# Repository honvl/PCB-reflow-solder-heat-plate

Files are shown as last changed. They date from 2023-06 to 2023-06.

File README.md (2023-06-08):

# PCB reflow solder heat plate

## Introduction

The PCB reflow solder heat plate can be used to solder small PCBs with SMD parts. The user can control the maximum temperature and heating curve. Buy a pre-assembled version here: https://www.tindie.com/products/littlethings/pcb-reflow-soldering-hot-plate/

## Hardware design

The idea for this design comes from https://github.com/AfterEarthLTD/Solder-Reflow-Plate. But when I checked the original design, I found some issues that could cause safety problems and other design choices that are not optimal.

## Hardware version 1.2

- Removed resettable fuse which was overheating and tripping
- Increased power supply capacitor ratings to 35V for 24V power supply compatibility
- Use 2 SMD capacitors for power supply capacitors instead of 4 standard ones for lower total board height
- Changed to easier to press switches

### Feature list

- PCB size 100x100mm, heat plate size 81x69mm
- DC barrel plug (5.5x2.5mm), runs with 12V/5A power supply
- inrush current limiter to protect power supply when capacitors are discharged
- 2.7mF input power filter for smooth current draw
- capacitor discharging resistors
- ATMEGA4809 MCU, can be programmed via UPDI header
- high power NMOS with gate driver circuit
- flyback diode connected to the heat plate
- AMS1117 LDO
- additional diodes for protection
- dual buttons
- status LED
- 0.91" OLED display
- LMT85 analog temperature sensor as main sensor
- option to add additional digital sensors for calibration purposes

### Building your own

You can order almost all parts needed from LCSC/JLCPCB. Only the OLED display and the power supply need to be sourced elsewhere. The BOM includes LCSC part numbers for hand soldering and their automated SMT manufacturing. Minimal part size is 0805 and there's enough space between all solder pads, so hand soldering should be no problem if you have a steady hand. Hardest part will be the MCU, but this is hand solderable, too.

### Safety measures compared to the original design

The original design had a too low heat plate resistance, which caused very high current spikes when the heat plate was turned on. This should be filtered by PWM and the input capacitors, but the input capacitor in the original design was far too small (100µF). Because of this, the fuse always blew when the device was turned on, so eventually the fuse was removed again.
In my design I made the input capacitors 27 times larger to have a smoother current draw. I also added a fuse, and an inrush current limiter. After disconnecting the power supply, the output capacitors are quickly discharged to GND.
The original also had no gate driver, so the NMOS was only driven with logic levels. I added a simple NPN gate driver.
Switching inductive loads (like the long heat plate trace) causes voltage spikes. In the original design, the filtering was done with an ESD diode and a small capacitor. The usual way to filter these voltage spikes is a flyback diode.
The resistance of the heat plate was very low, so the current draw with 100% PWM duty cycle was very high. If the MCUs hangs up and the power MOSFET stays active, the original design could cause too much stress for the power supply. Furthermore, even with a hot heat plate, the resistance would still be so low that the board would draw more than 5A.
In my design, the heat plate resistance was chosen in a way that a hot heat plate will draw less than 5A, so it is much safer to run the new design, as it will automatically reach electrically safe working conditions.

## Firmware

The original firmware was reworked by Nathan Heidt (https://github.com/heidtn) and works mostly, only the temperature sensing is incorrect (as the firmware was written with an earlier board revision). So for now, you just need to unplug the device when the PCB that needed soldering is done. Also, the dual color LED is not yet included into the code, for now it just lights green to show power. And the buttons sometimes don't react properly.

Daniel Oltmanns (https://github.com/oltdaniel) is doing a rework of the firmware using platformio.

### To-do list for software:
- use of the dual color LED (green = power, orange = heating, red = hot)
- better temperature sensing
- better working buttons
- calibration function for the analog temperature sensor by taping a digital probe directly to the heat plate

Please note that I can only do hardware design, so I can't contribute anything to the software. 

### Programming the MCU

The MCU can be programmed with JTAG2UPDI (https://github.com/ElTangas/jtag2updi). For programming, you need an Arduino with ATMEGA328p (Uno or Nano), some wires, a 4.7k resistor and  a 10µF capacitor or 120 Ohm resistor to disable the auto-reset.

JCM from the Discord explained the process pretty good:

> 1. Download/Clone this project: https://github.com/ElTangas/jtag2updi and rename the folder "source" to "jtag2updi" (otherwise the Arduino IDE won't like it)
> 2. Open jtag2updi/jtag2updi.ino in your Arduino IDE
> 3. Configure the flasher options for your Arduino Nano and flash it
> 4. Connect D6 of your Arduino Nano over the 4.7kOhm resistor to the UPDI pin of the board and 5V to 5V and GND to 0V
> 5. Add the MegaCoreX hardware package to the Ardunio IDE (see https://github.com/MCUdude/MegaCoreX#how-to-install)
> 6. Install the Adafruit_GFX, Adafruit_SSD1306, DallasTemperature and Debounce2 libraries with the Library Manager (you might not need all of them depending on which firmware you plan to use)
> 7. Download and open the ino you want to upload to the ATMEGA4809 (https://github.com/DerSpatz/PCB-reflow-solder-heat-plate/blob/main/Firmware/pcb_reflow_fw/pcb_reflow_fw.ino)
> 8. Select the options for the programmer (Board: ATmega4809, Clock: Internal 16 MHz, BOD: 2.6V or 2.7V, EEPROM: retained, Pinout: 48 pin standard, Reset pin: Reset, no Bootloader) and select the port of your Ardunio Nano as Port
> 9. Select Burn Bootloader and see if it runs through
> 10. Temporarily disable auto reset for the Arduino Nano: https://playground.arduino.cc/Main/DisablingAutoResetOnSerialConnection/ (not sure if it's needed for the Nano, it was for my Mega)
> 11. Select Sketch > Upload using Programmer (normal Upload will not work)

## Thanks

Special Thanks go out to:

Nathan Heidt for writing the software and testing

Merlin Shaw (www.facebook.com/GeekIslandGaming) for ordering the first batch of prototypes and testing

heatplate PCB front
heatplate PCB back

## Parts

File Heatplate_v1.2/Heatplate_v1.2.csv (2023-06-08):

Comment | Designator | Footprint | LCSC Part #
10u Unpolarized capacitor, small symbol | C1 | C_0805_2012Metric | C162422
100-680u/35V Polarized capacitor, small symbol | C2,C5 | CP_Elec_8x10 | C882163
22u/35V Polarized capacitor, small symbol | C6,C7 | CP_Elec_5x5.4 | C239256
470pF Unpolarized capacitor, small symbol | C8 | C_0805_2012Metric | C1743
100nF Unpolarized capacitor, small symbol | C9,C10,C11,C12,C13 | C_0805_2012Metric | C1711
B5819W Diode, small symbol, filled shape | D1,D2,D3,D4 | D_SOD-123 | C64885
M3 Mounting Hole without connection | H1,H2,H3,H4 | MountingHole_3.2mm_M3 | C551332
Barrel_Jack_Switch DC Barrel Jack with an internal switch | J1 | BarrelJack_Horizontal | C381115
RED/GREEN Light emitting diode, small symbol, filled shape | LED1 | LED_Avago_PLCC4_3.2x2.8mm_CW | C131251
SSD1306 SSD1306 OLED | OLED1 | 0.91Inch-OLED-Module | C2718488
WSP4409A N-MOSFET transistor, drain/gate/source | Q1 | SOIC-8_3.9x4.9mm_P1.27mm | C2880527
IRLR8726TRPBF N-MOSFET transistor, gate/drain/source | Q2 | TO-252-2 | C81137
SS8050 NPN transistor, base/emitter/collector | Q3 | SOT-23 | C444722
47 Resistor, small symbol | R1,R2 | R_0805_2012Metric | C17714
1k Resistor, small symbol | R3,R5,R6,R7 | R_0805_2012Metric | C17513
4k7 Resistor, small symbol | R4,R8,R9,R10 | R_0805_2012Metric | C17673
10k Resistor, small symbol | R11,R12,R13,R14,R15 | R_0805_2012Metric | C17414
SW_Push Push button switch, generic, two pins | SW1,SW2 | SW_PUSH_6mm | C93151
LMT85 Precision centigrade temperature sensor, TO-92 | TEMP1 | TO-92_Inline | C75856
DS18B20Z Programmable Resolution 1-Wire Digital Thermometer SOIC-8 | TEMP2 | SOIC-8_3.9x4.9mm_P1.27mm | C695837
Ext. 1-Wire Programmable Resolution 1-Wire Digital Thermometer TO-92 | TEMP3 | PinHeader_1x03_P2.54mm_Vertical
TestPoint test point | TP1,TP2,TP3 | TestPoint_Pad_D1.5mm
ATMEGA4809-AFR MICROCHIP - ATMEGA4809-AFR - MCU, 8BIT, ATMEGA, 20MHZ, TQFP-48 | U1 | TQFP-48_7x7mm_P0.5mm | C189475
AMS1117-5.0 1A Low Dropout regulator, positive, 5.0V fixed output, SOT-223 | U2 | SOT-89-3 | C351450
1x03_2.54mm Generic connector, single row, 01x03, script generated (kicad-library-utils/schlib/autogen/connector/) | UPDI1 | PinHeader_1x03_P2.54mm_Vertical | C49257

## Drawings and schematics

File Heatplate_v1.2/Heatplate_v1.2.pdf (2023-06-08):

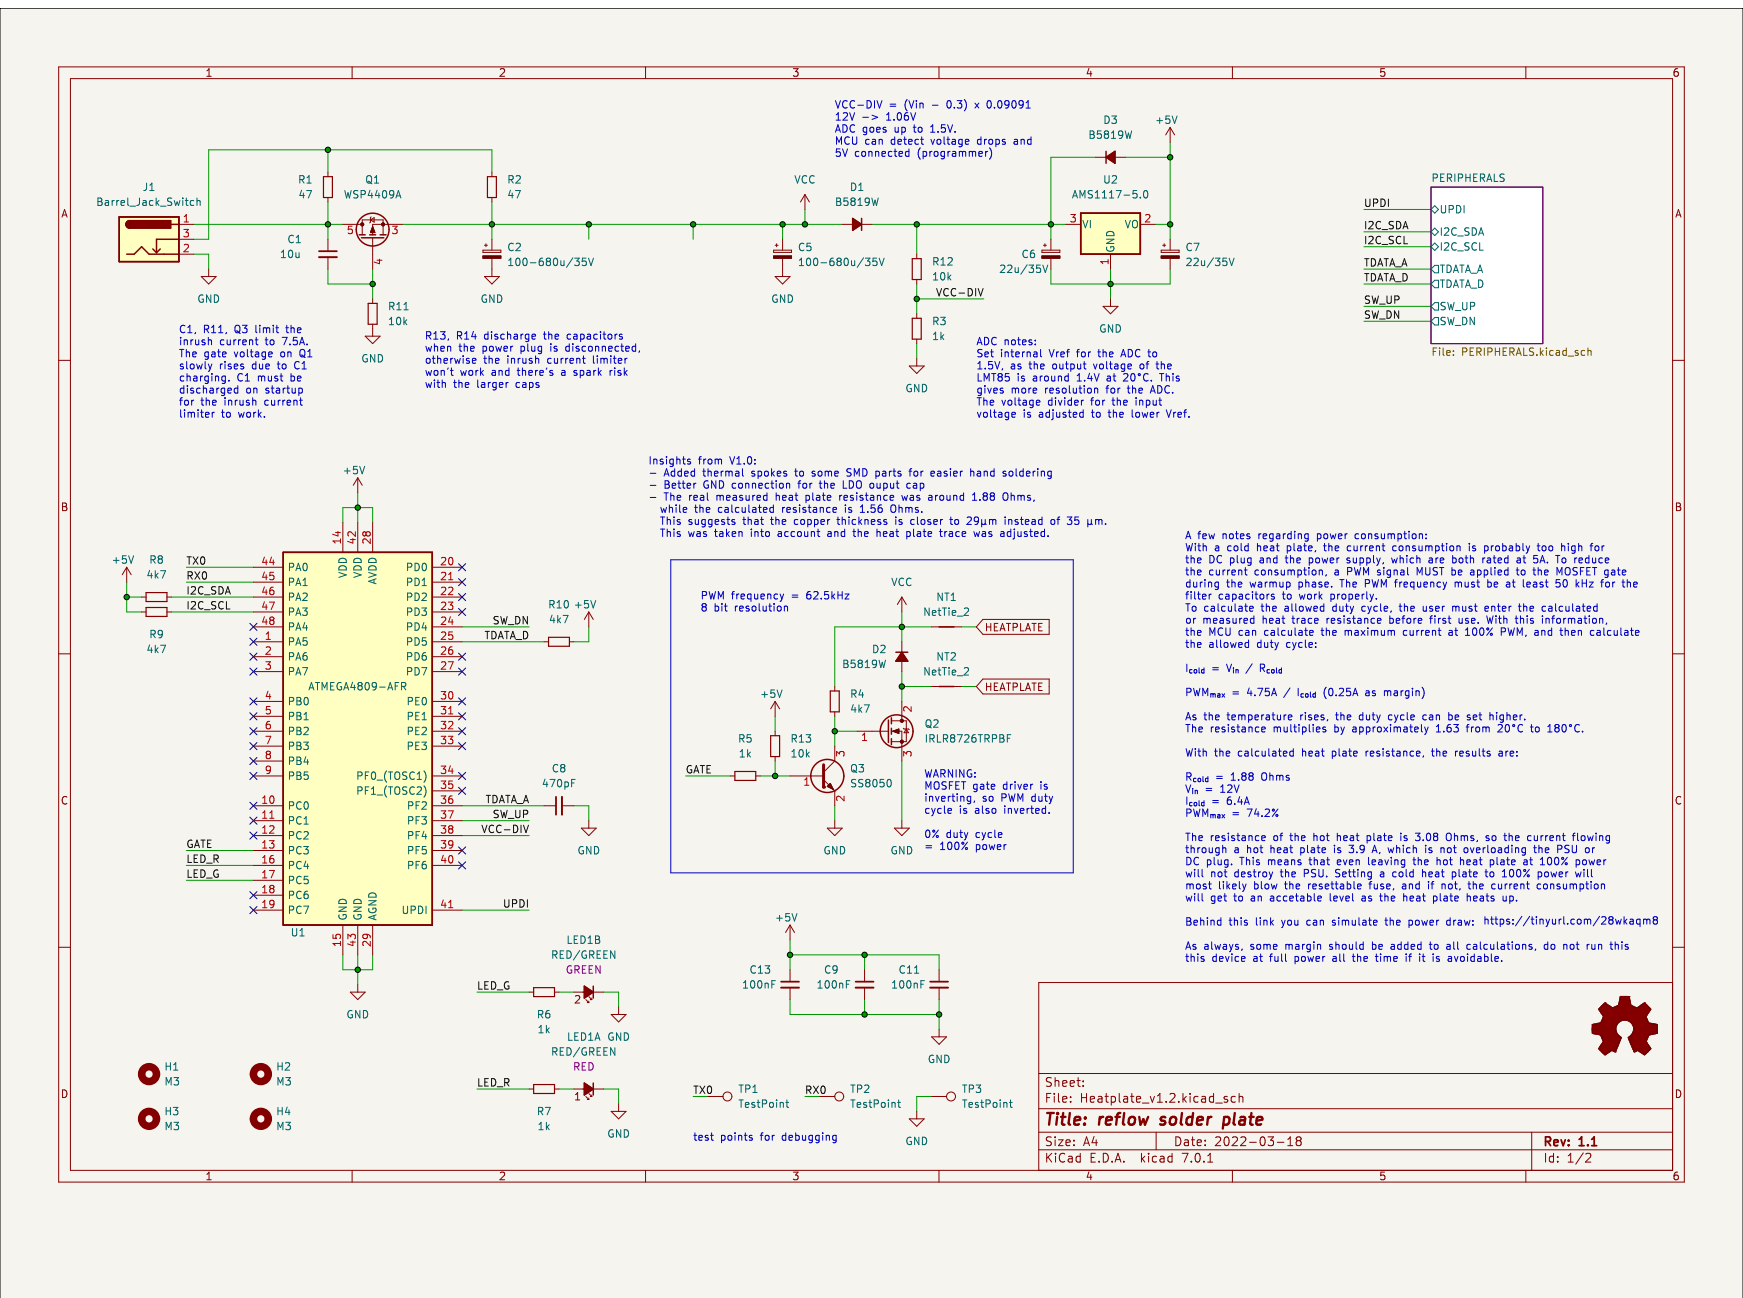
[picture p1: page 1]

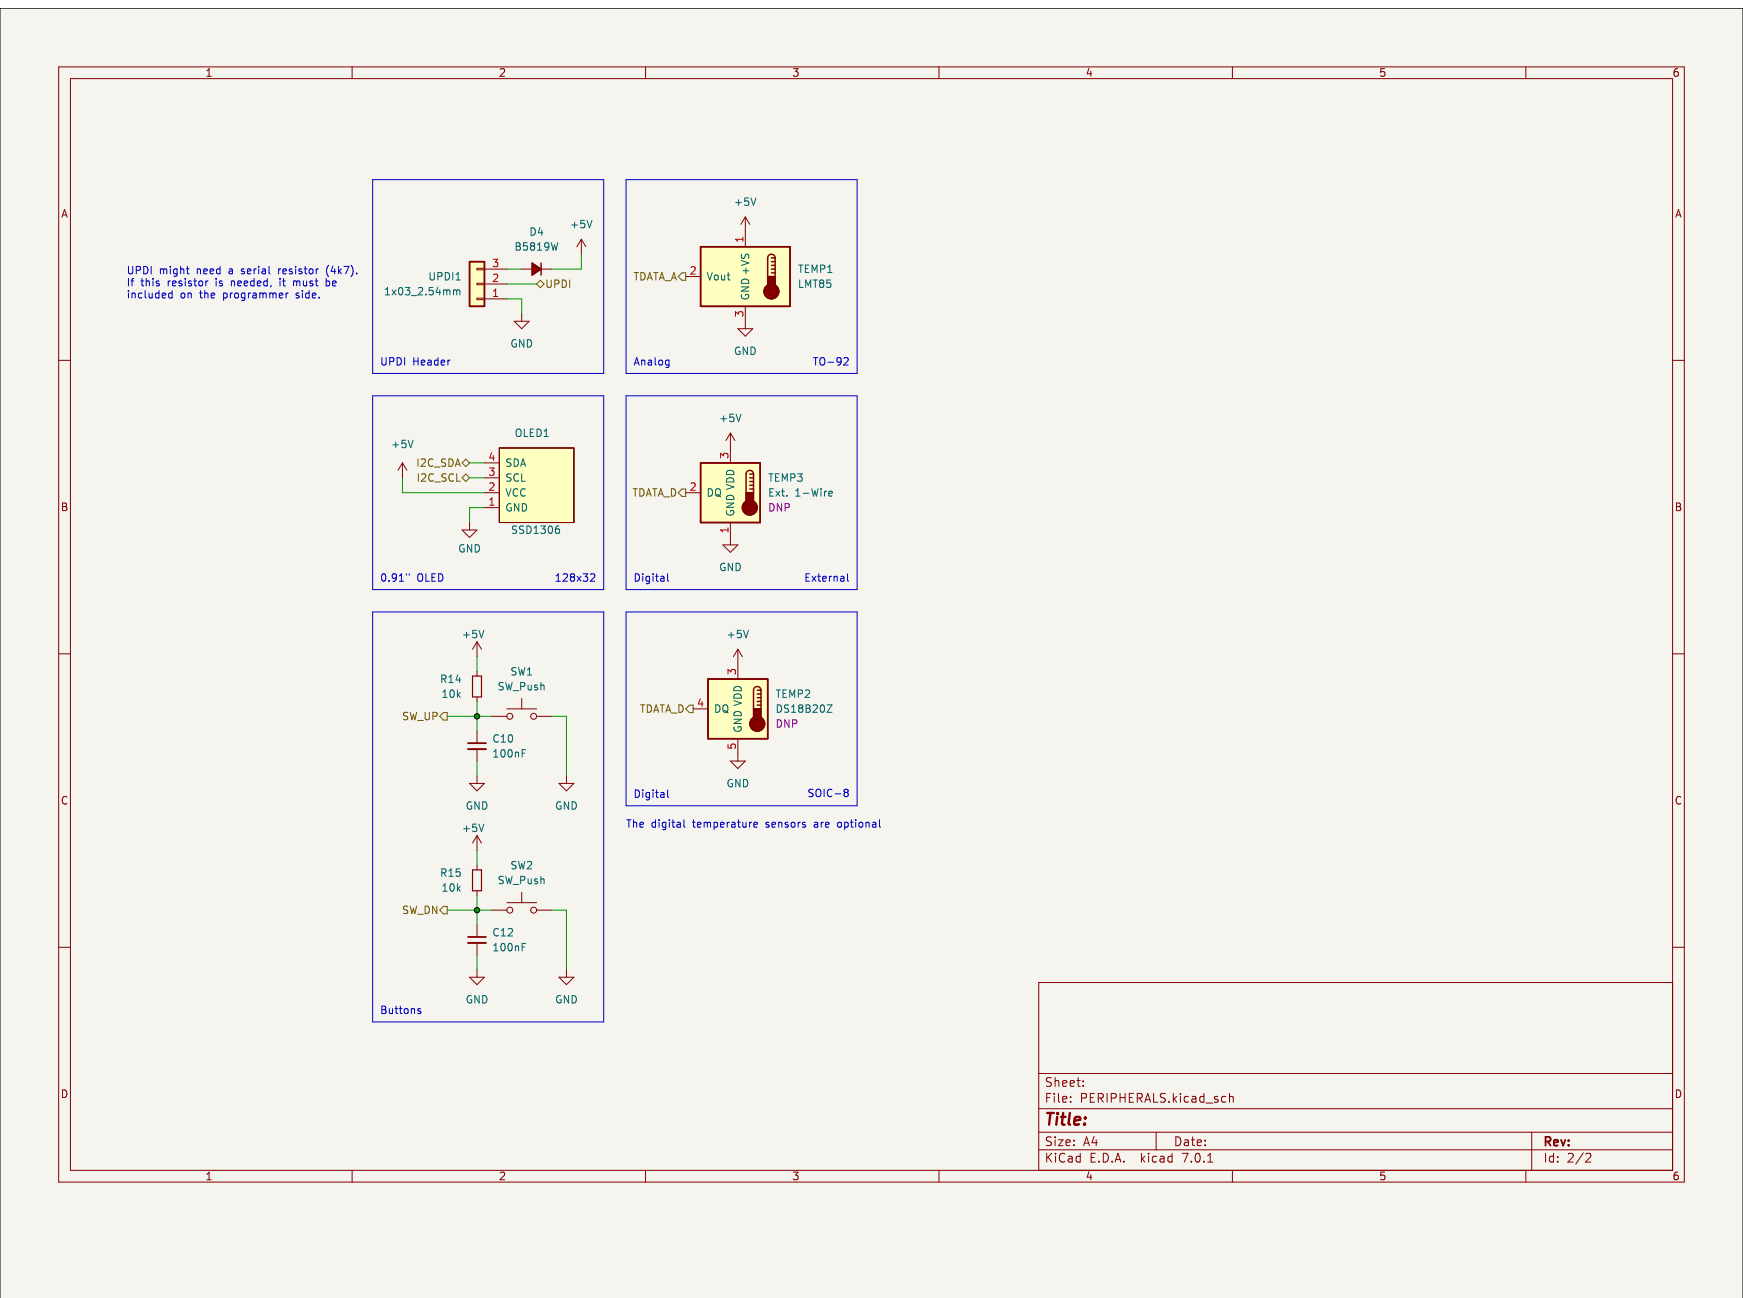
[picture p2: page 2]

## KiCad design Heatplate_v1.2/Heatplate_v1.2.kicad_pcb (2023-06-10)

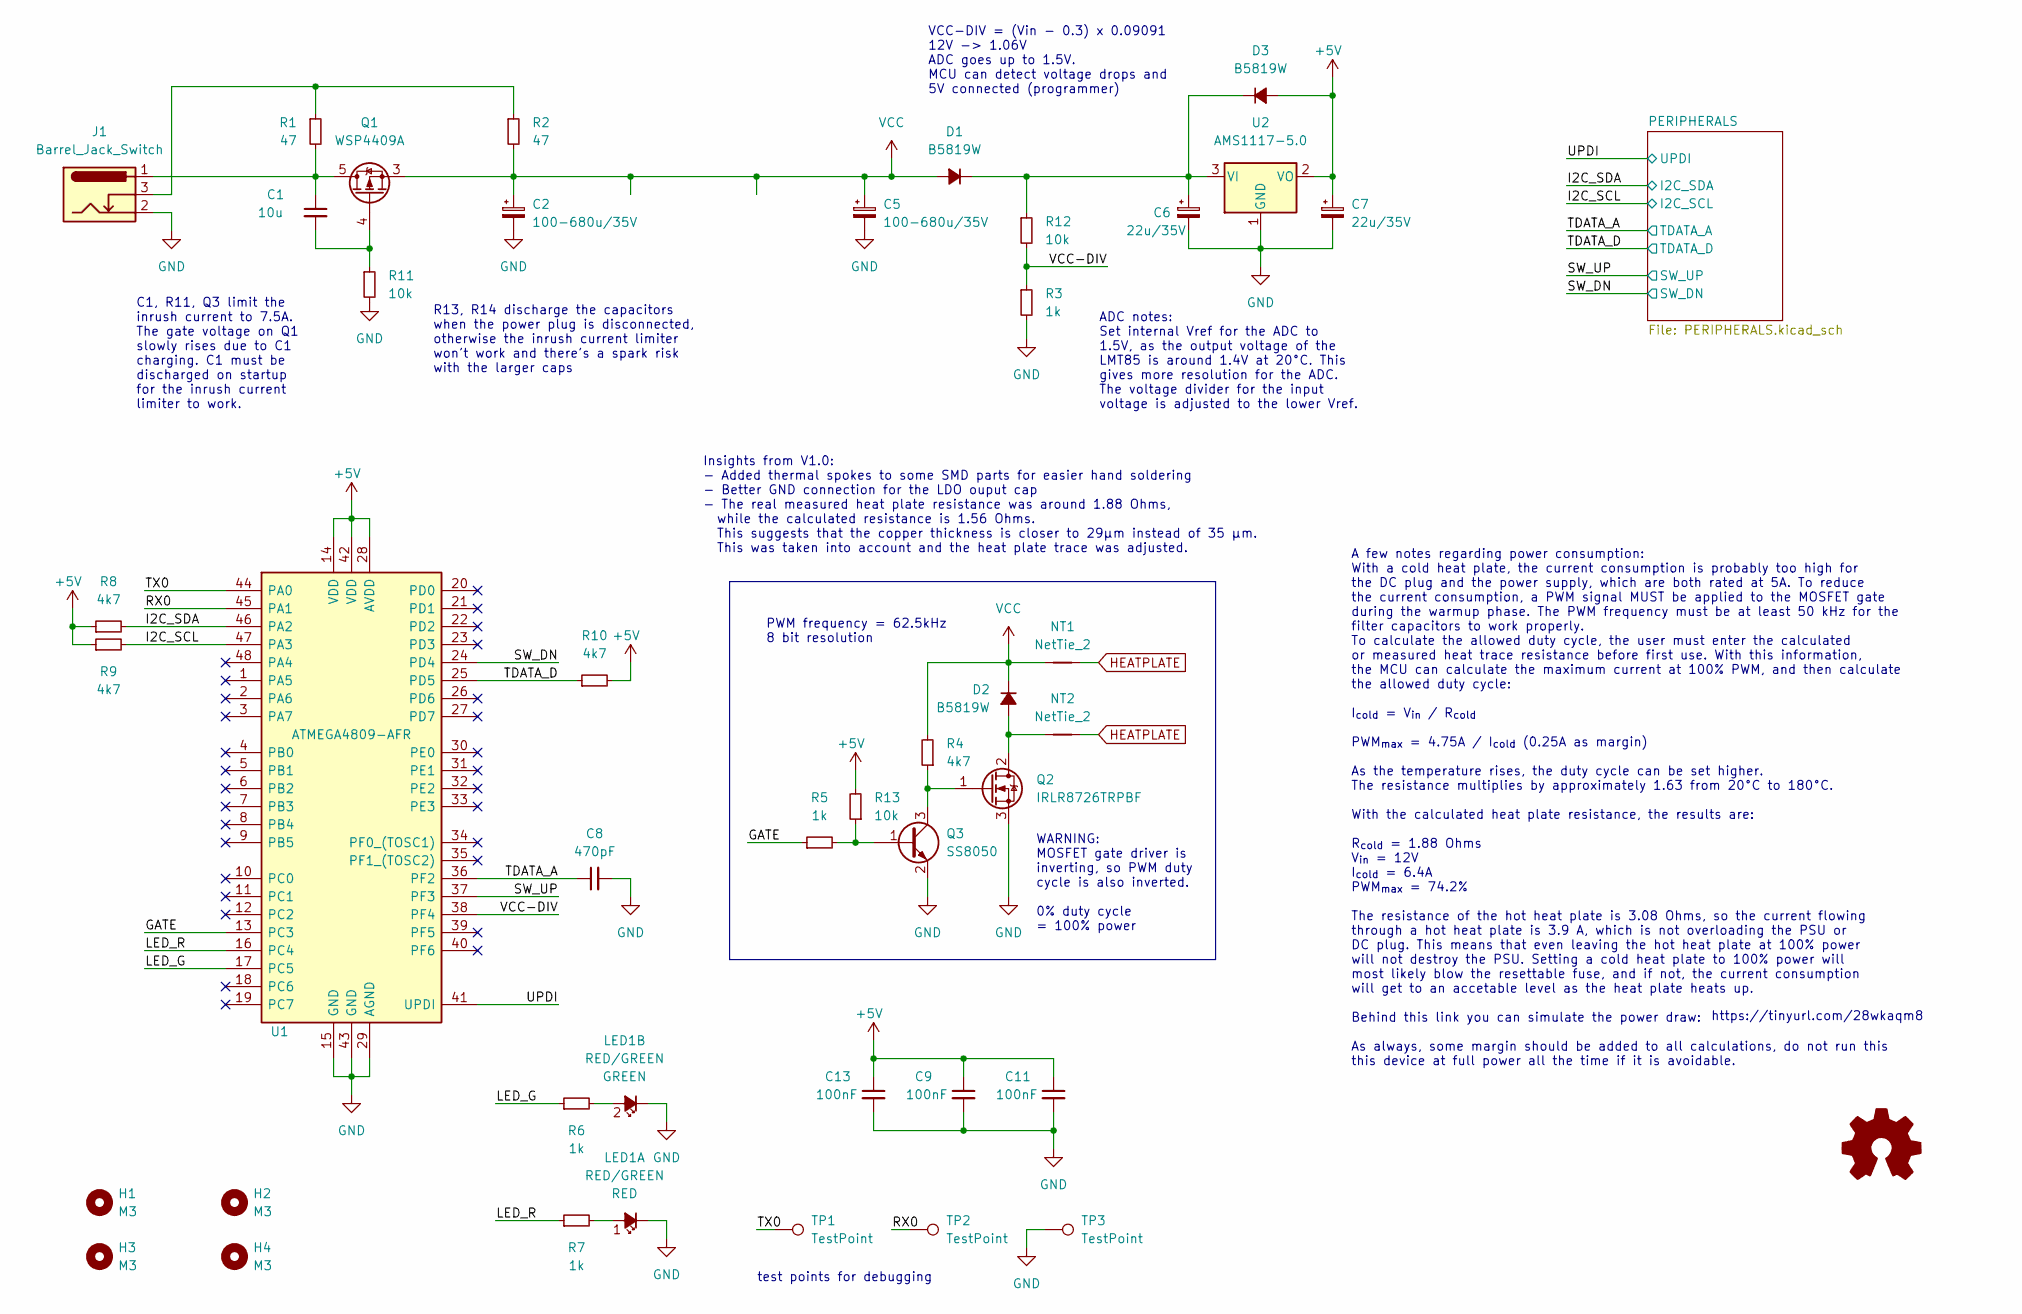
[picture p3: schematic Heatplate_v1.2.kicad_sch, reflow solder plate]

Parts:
C1: 10u; C_0805_2012Metric; LCSC Part Number C162422
C2, C5: 100-680u/35V; CP_Elec_8x10; LCSC Part Number C882163
C6, C7: 22u/35V; CP_Elec_5x5.4; LCSC Part Number C239256
C8: 470pF; C_0805_2012Metric; LCSC Part Number C1743
C9, C11, C13: 100nF; C_0805_2012Metric; LCSC Part Number C1711
D1, D2, D3: B5819W; D_SOD-123; LCSC Part Number C64885
H1, H2, H3, H4: M3; MountingHole_3.2mm_M3; LCSC Part Number C551332
J1: Barrel_Jack_Switch; BarrelJack_Horizontal; LCSC Part Number C381115
LED1: RED/GREEN; LED_Avago_PLCC4_3.2x2.8mm_CW; LCSC Part Number C131251
LOGO1: Logo_Open_Hardware_Small; OSHW-Logo2_7.3x6mm_SilkScreen
NT1, NT2: NetTie_2; NetTie-2_SMD_Pad1.3mm
Q1: WSP4409A; SOIC-8_3.9x4.9mm_P1.27mm; LCSC Part Number C2880527
Q2: IRLR8726TRPBF; TO-252-2; LCSC Part Number C81137
Q3: SS8050; SOT-23; LCSC Part Number C444722
R1, R2: 47; R_0805_2012Metric; LCSC Part Number C17714
R3, R5, R6, R7: 1k; R_0805_2012Metric; LCSC Part Number C17513
R4, R8, R9, R10: 4k7; R_0805_2012Metric; LCSC Part Number C17673
R11, R12, R13: 10k; R_0805_2012Metric; LCSC Part Number C17414
TP1, TP2, TP3: TestPoint; TestPoint_Pad_D1.5mm
U1: ATMEGA4809-AFR; TQFP-48_7x7mm_P0.5mm; Manufacturer_Part_Number ATMEGA4809-AFR; Mouser Part Number 556-ATMEGA4809-AFR
U2: AMS1117-5.0; SOT-89-3; LCSC Part Number C351450

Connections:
+5V: C7.1, C9.1, C11.1, C13.1, D3.2 (A), R8.1, R9.1, R10.2, R13.2, U1.14 (VDD), U1.28 (AVDD), U1.42 (VDD), U2.2 (VO); also elsewhere on the board
/GATE: R5.1, U1.13 (PC3)
/I2C_SCL: R9.2, U1.47 (PA3); also elsewhere on the board
/I2C_SDA: R8.2, U1.46 (PA2); also elsewhere on the board
/LED_G: R6.1, U1.17 (PC5)
/LED_R: R7.1, U1.16 (PC4)
/RX0: TP2.1, U1.45 (PA1)
/SW_DN: U1.24 (PD4); also elsewhere on the board
/SW_UP: U1.37 (PF3); also elsewhere on the board
/TDATA_A: C8.1, U1.36 (PF2); also elsewhere on the board
/TDATA_D: R10.1, U1.25 (PD5); also elsewhere on the board
/TX0: TP1.1, U1.44 (PA0)
/UPDI: U1.41 (UPDI); also elsewhere on the board
/VCC-DIV: R3.1, R12.2, U1.38 (PF4)
GND: C2.2, C5.2, C6.2, C7.2, C8.2, C9.2, C11.2, C13.2, J1.2, LED1.2 (K1), LED1.4 (K2), Q2.3 (S), Q3.2 (E), R3.2, R11.2, TP3.1, U1.15 (GND), U1.29 (AGND), U1.43 (GND), U2.1 (GND); also elsewhere on the board
HEATPLATE: NT1.2, NT2.2
unnamed: C1.1, J1.1, Q1.5 (D), Q1.6 (D), Q1.7 (D), Q1.8 (D), R1.2
unnamed: C6.1, D1.1 (K), D3.1 (K), R12.1, U2.3 (VI)
unnamed: D2.2 (A), NT2.1, Q2.2 (D)
unnamed: J1.3, R1.1, R2.1
unnamed: LED1.1 (A1), R7.2
unnamed: LED1.3 (A2), R6.2
unnamed: C1.2, Q1.4 (G), R11.1
unnamed: Q2.1 (G), Q3.3 (C), R4.1
unnamed: Q3.1 (B), R5.2, R13.1
VCC: C2.1, C5.1, D1.2 (A), D2.1 (K), NT1.1, Q1.1 (S), Q1.2 (S), Q1.3 (S), R2.2, R4.2

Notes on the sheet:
C1, R11, Q3 limit the inrush current to 7.5A. The gate voltage on Q1 slowly rises due to C1 charging. C1 must be discharged on startup for the inrush current limiter to work.
VCC-DIV = (Vin - 0.3) x 0.09091 12V -> 1.06V ADC goes up to 1.5V. MCU can detect voltage drops and 5V connected (programmer)
PWM frequency = 62.5kHz 8 bit resolution
A few notes regarding power consumption: With a cold heat plate, the current consumption is probably too high for the DC plug and the power supply, which are both rated at 5A. To reduce the current consumption, a PWM signal MUST be applied to the MOSFET gate during the warmup phase. The PWM frequen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
WARNING: MOSFET gate driver is inverting, so PWM duty cycle is also inverted. 0% duty cycle = 100% power
R13, R14 discharge the capacitors when the power plug is disconnected, otherwise the inrush current limiter won't work and there's a spark risk with the larger caps
https://tinyurl.com/28wkaqm8
test points for debugging
ADC notes: Set internal Vref for the ADC to 1.5V, as the output voltage of the LMT85 is around 1.4V at 20°C. This gives more resolution for the ADC. The voltage divider for the input voltage is adjusted to the lower Vref.
Insights from V1.0: - Added thermal spokes to some SMD parts for easier hand soldering - Better GND connection for the LDO ouput cap - The real measured heat plate resistance was around 1.88 Ohms, while the calculated resistance is 1.56 Ohms. This suggests that the copper thickness is closer to 29µ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

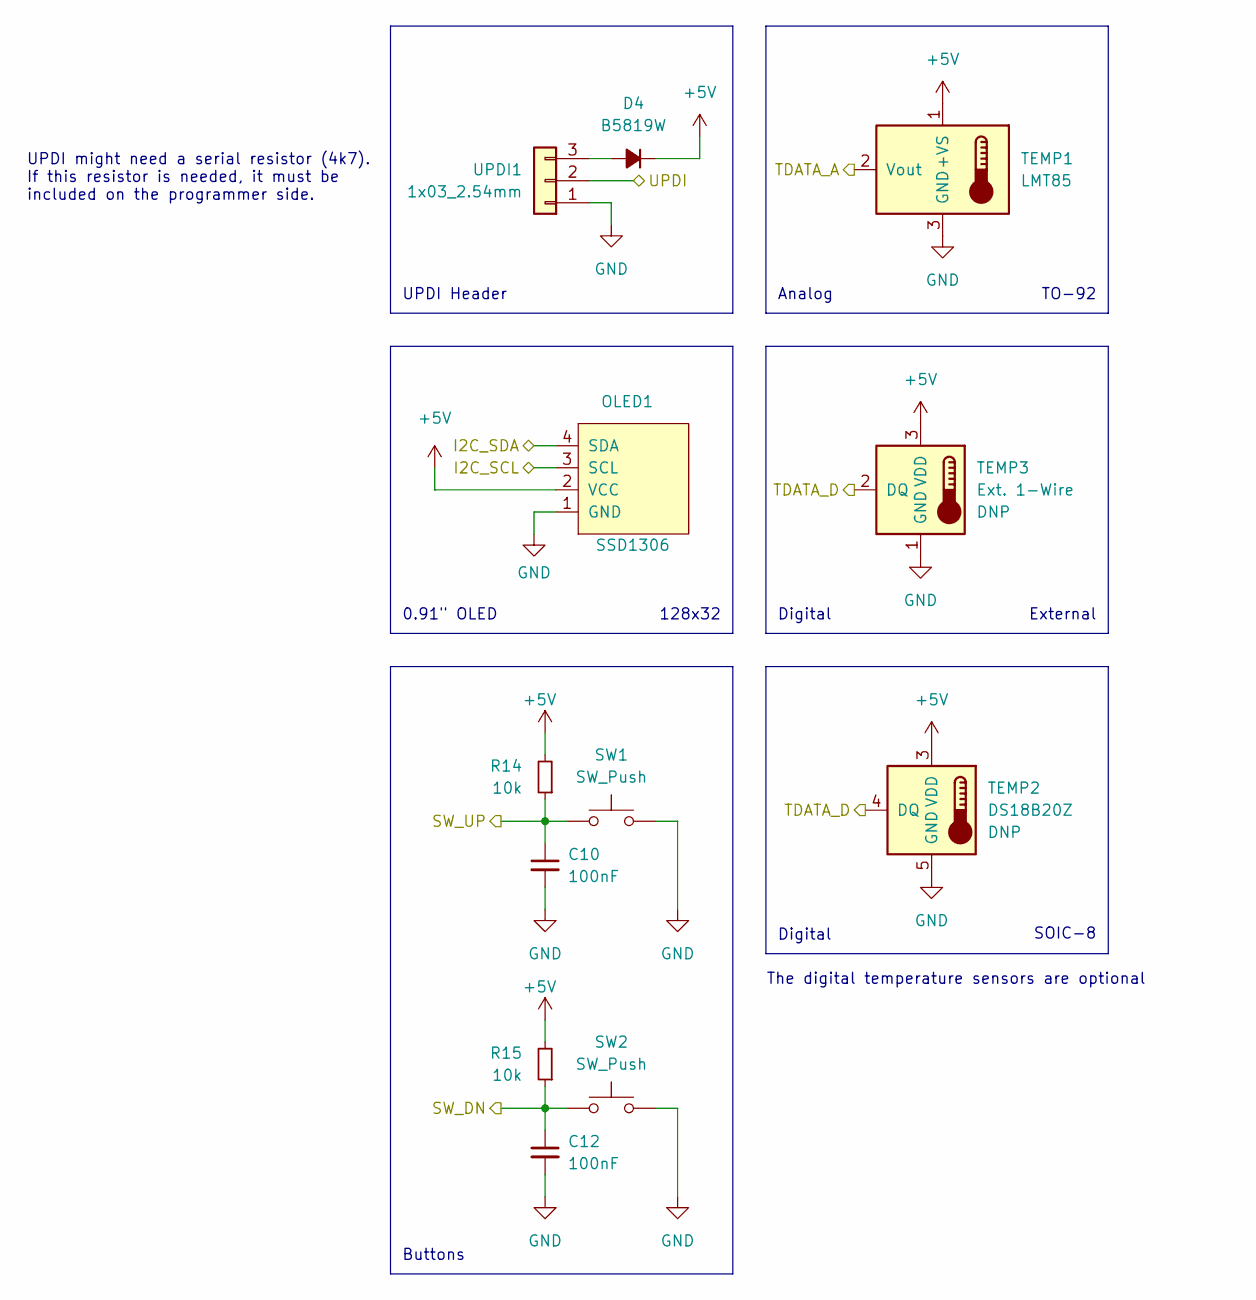
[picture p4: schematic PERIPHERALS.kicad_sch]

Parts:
C10, C12: 100nF; C_0805_2012Metric; LCSC Part Number C1711
D4: B5819W; D_SOD-123; LCSC Part Number C64885
OLED1: SSD1306; 0.91Inch-OLED-Module; LCSC Part Number C2718488
R14, R15: 10k; R_0805_2012Metric; LCSC Part Number C17414
SW1, SW2: SW_Push; SW_PUSH_6mm; LCSC Part Number C93151
TEMP1: LMT85; TO-92_Inline; LCSC Part Number C75856
TEMP2: DS18B20Z; SOIC-8_3.9x4.9mm_P1.27mm; LCSC Part Number C695837
TEMP3: Ext. 1-Wire; PinHeader_1x03_P2.54mm_Vertical
UPDI1: 1x03_2.54mm; PinHeader_1x03_P2.54mm_Vertical; LCSC Part Number C49257

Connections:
+5V: D4.1 (K), OLED1.2 (VCC), R14.2, R15.2, TEMP1.1 (+VS), TEMP2.3 (VDD), TEMP3.3 (VDD); also elsewhere on the board
/I2C_SCL: OLED1.3 (SCL); also elsewhere on the board
/I2C_SDA: OLED1.4 (SDA); also elsewhere on the board
/SW_DN: C12.1, R15.1, SW2.1; also elsewhere on the board
/SW_UP: C10.1, R14.1, SW1.1; also elsewhere on the board
/TDATA_A: TEMP1.2 (Vout); also elsewhere on the board
/TDATA_D: TEMP2.4 (DQ), TEMP3.2 (DQ); also elsewhere on the board
/UPDI: UPDI1.2; also elsewhere on the board
GND: C10.2, C12.2, OLED1.1 (GND), SW1.2, SW2.2, TEMP1.3 (GND), TEMP2.5 (GND), TEMP3.1 (GND), UPDI1.1; also elsewhere on the board
unnamed: D4.2 (A), UPDI1.3

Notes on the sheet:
SOIC-8
Digital
UPDI Header
128x32
Analog
TO-92
0.91" OLED
The digital temperature sensors are optional
Buttons
UPDI might need a serial resistor (4k7). If this resistor is needed, it must be included on the programmer side.
External

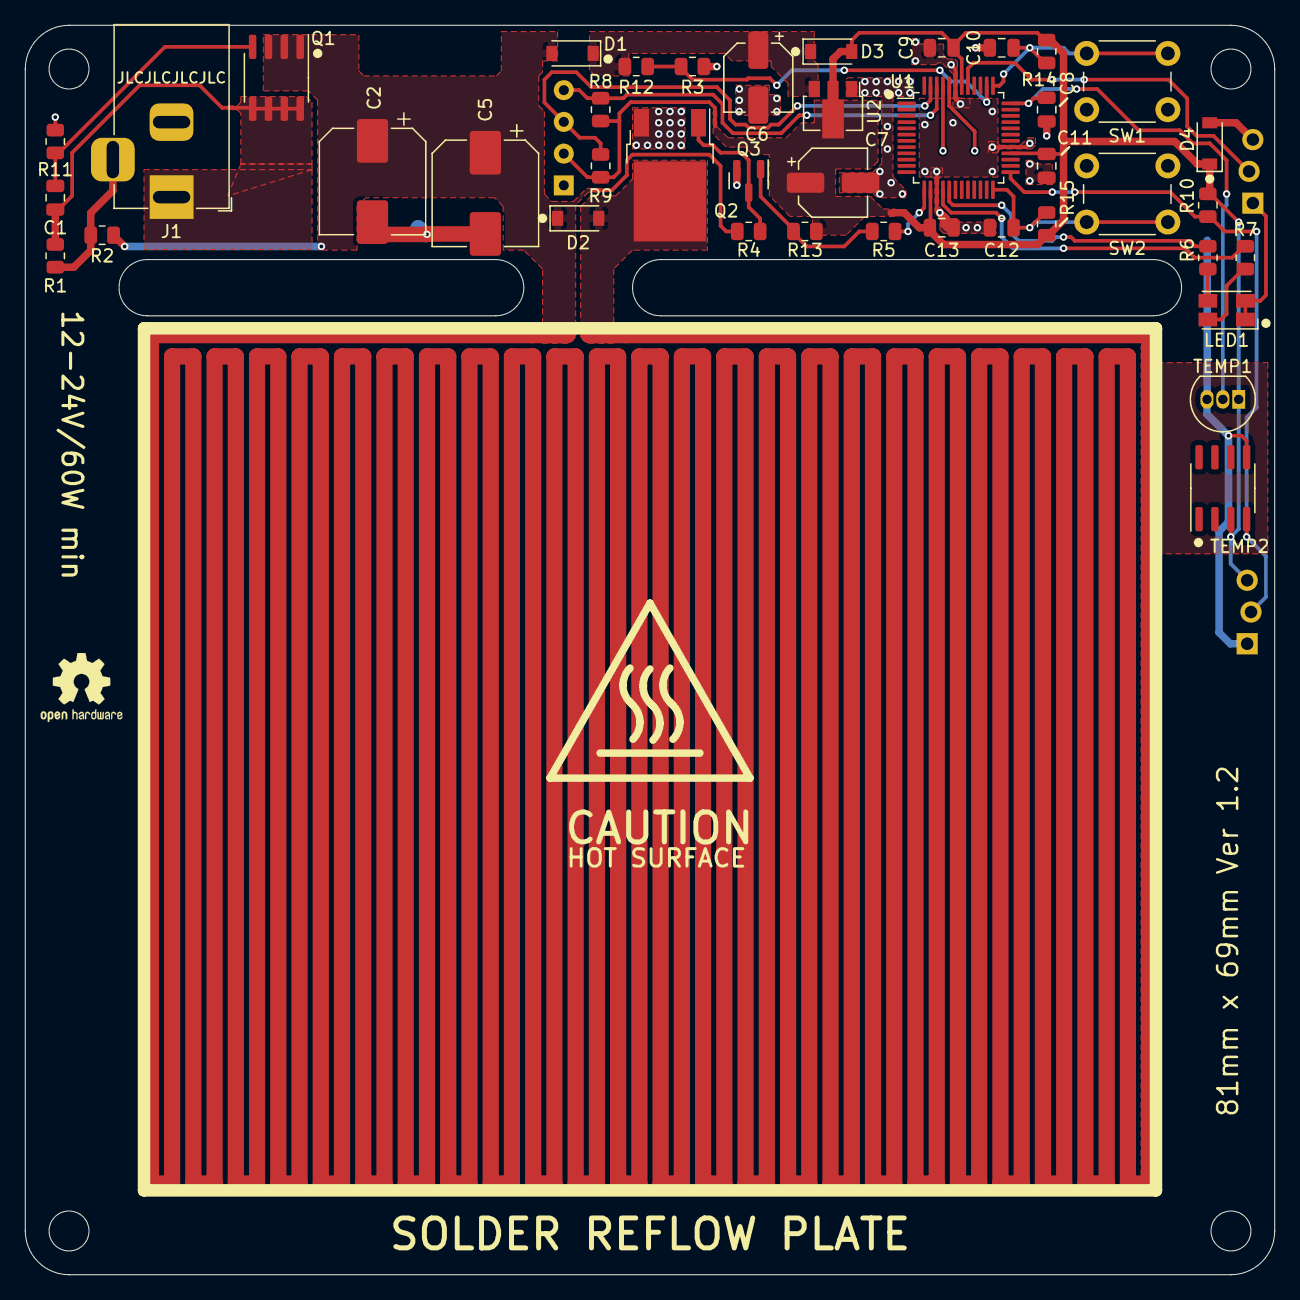
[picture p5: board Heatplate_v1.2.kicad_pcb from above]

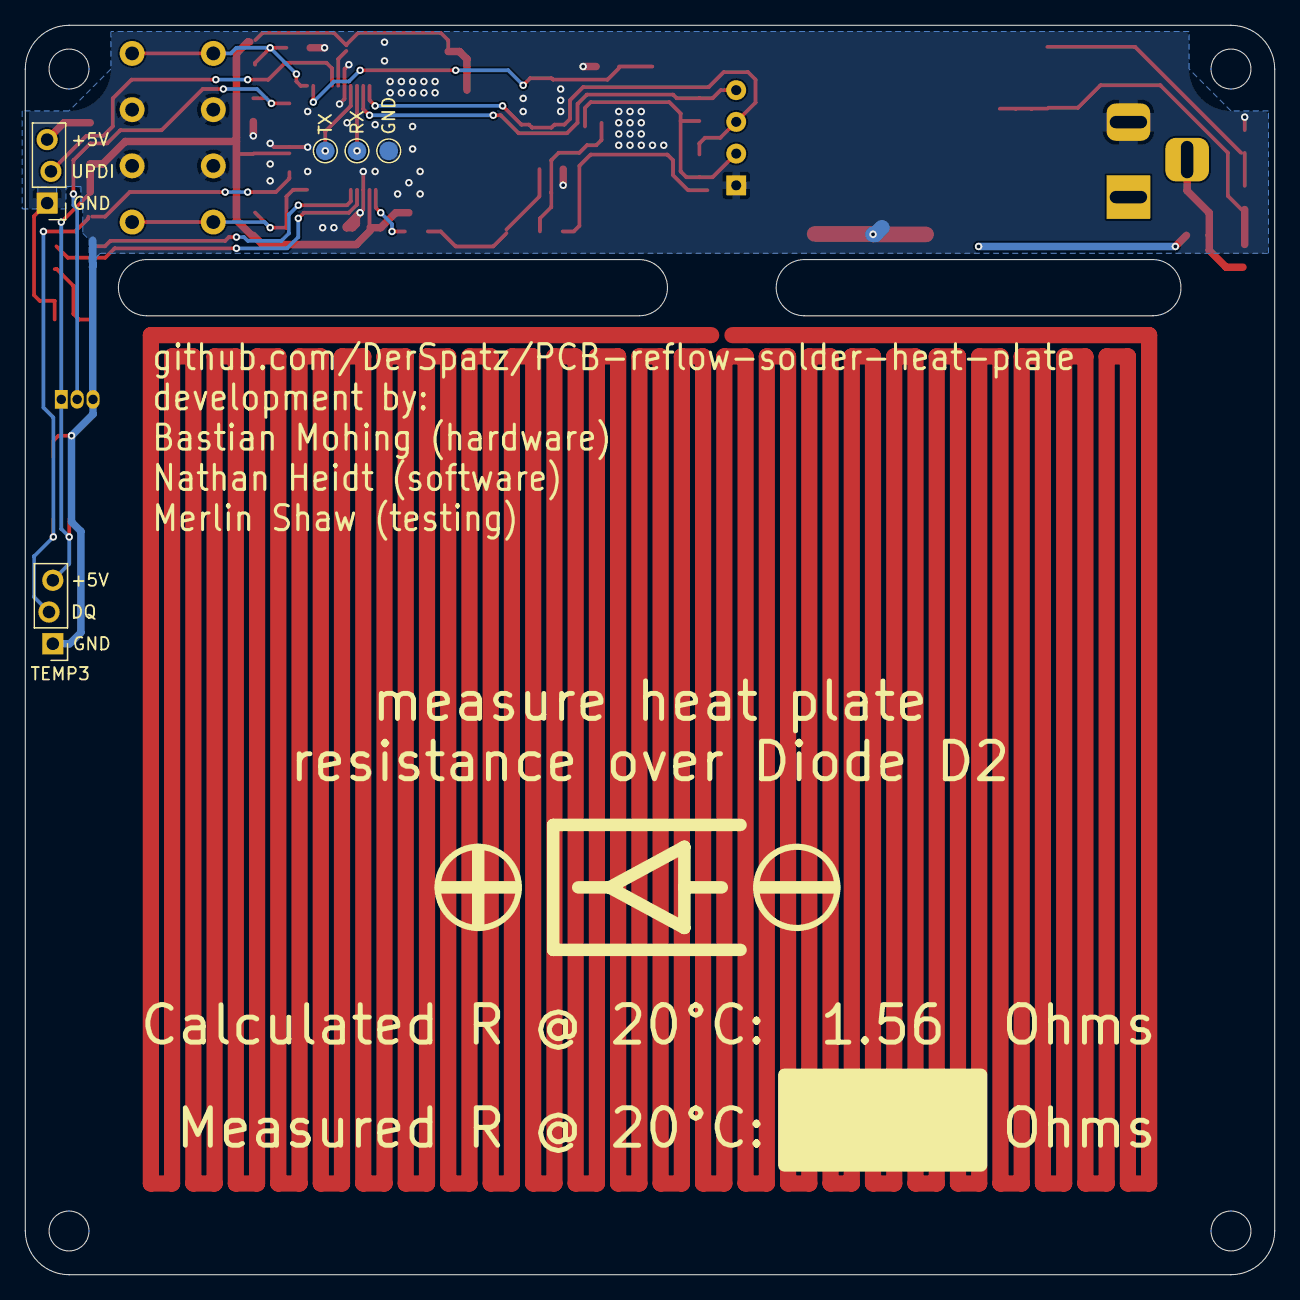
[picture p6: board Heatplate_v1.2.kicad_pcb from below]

Board: 2 copper layers, 100.0 x 100.0 mm, 54 parts (5 on the bottom side), 27 nets.

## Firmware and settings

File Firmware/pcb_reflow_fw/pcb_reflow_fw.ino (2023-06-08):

/* Solder Reflow Plate Sketch
 *  H/W - Ver Spatz-1.1
 *  S/W - Ver 1.1
 *  by Chris Halsall and Nathan Heidt     */

/* To prepare
 * 1) Install MiniCore in additional boards; (copy into File->Preferences->Additional Boards Manager
 * URLs) https://mcudude.github.io/MiniCore/package_MCUdude_MiniCore_index.json 2) Then add MiniCore
 * by searching and installing (Tools->Board->Board Manager) 3) Install Adafruit_GFX and
 * Adafruit_SSD1306 libraries (Tools->Manage Libraries)
 */

/* To program
 *  1) Select the following settings under (Tools)
 *      Board->Minicore->Atmega328
 *      Clock->Internal 8MHz
 *      BOD->BOD 2.7V
 *      EEPROM->EEPROM retained
 *      Compiler LTO->LTO Disabled
 *      Variant->328P / 328PA
 *      Bootloader->No bootloader
 *  2) Set programmer of choice, e.g.'Arduino as ISP (MiniCore)', 'USB ASP', etc, and set correct
 * port. 3) Burn bootloader (to set fuses correctly) 4) Compile and upload
 *
 *
 * TODOS:
 * - add digital sensor setup routine if they are detected, but not setup
 * - figure out a method for how to use all the temperature sensors
 * - implement an observer/predictor for the temperature sensors.  Kalman filter time?!?
 */

#include <Adafruit_GFX.h>
#include <Adafruit_SSD1306.h>
#include <DallasTemperature.h>
#include <EEPROM.h>
#include <OneWire.h>
#include <SPI.h>
#include <SimpleKalmanFilter.h>

// Version Definitions
static const PROGMEM float hw = 1.1;
static const PROGMEM float sw = 1.1;

// Screen Definitions
#define SCREEN_WIDTH 128
#define SCREEN_HEIGHT 32
#define SCREEN_ADDRESS 0x3C                                       // I2C Address
Adafruit_SSD1306 display(SCREEN_WIDTH, SCREEN_HEIGHT, &Wire, -1); // Create Display

// Pin Definitions
#define MOSFET_PIN PIN_PC3
#define UPSW_PIN PIN_PF3
#define DNSW_PIN PIN_PD4
#define TEMP_PIN PIN_PF2 // A2
#define VCC_PIN PIN_PF4  // A0
#define LED_GREEN_PIN PIN_PC5
#define LED_RED_PIN PIN_PC4
#define ONE_WIRE_BUS PIN_PD5

#define MOSFET_PIN_OFF 255

enum menu_state_t { MENU_IDLE, MENU_SELECT_PROFILE, MENU_HEAT, MENU_INC_TEMP, MENU_DEC_TEMP };
enum buttons_state_t { BUTTONS_NO_PRESS, BUTTONS_BOTH_PRESS, BUTTONS_UP_PRESS, BUTTONS_DN_PRESS };
enum single_button_state_t { BUTTON_PRESSED, BUTTON_RELEASED, BUTTON_NO_ACTION };

// Button interrupt state
volatile single_button_state_t up_button_state = BUTTON_NO_ACTION;
volatile single_button_state_t dn_button_state = BUTTON_NO_ACTION;
volatile unsigned long up_state_change_time = 0;
volatile unsigned long down_state_change_time = 0;

// Temperature Info
byte max_temp_array[] = { 130,135,140,145,150,155 };
byte max_temp_index = 0;
#define MAX_RESISTANCE 10.0
float bed_resistance = 1.30;
#define MAX_AMPERAGE 5
#define PWM_VOLTAGE_SCALAR 2.0

// These values were derived using a regression from real world data.
// See the jupyter notebooks for more detail
#define ANALOG_APPROXIMATION_SCALAR 1.612
#define ANALOG_APPROXIMATION_OFFSET -20.517

// EEPROM storage locations
#define CRC_ADDR 0
#define FIRSTTIME_BOOT_ADDR 4
#define TEMP_INDEX_ADDR 5
#define RESISTANCE_INDEX_ADDR 6
#define DIGITAL_TEMP_ID_ADDR 10

// Voltage Measurement Info
#define VOLTAGE_REFERENCE 1.5


// Solder Reflow Plate Logo
static const uint8_t PROGMEM logo[] = {
    0x00, 0x00, 0x00, 0x01, 0x00, 0x00, 0x00, 0x00, 0x00, 0x00, 0x00, 0x00, 0x00, 0x00, 0x00, 0x00,
    0x00, 0x00, 0x00, 0x01, 0x80, 0x00, 0x00, 0x00, 0x00, 0x00, 0x1f, 0x00, 0x00, 0x00, 0x00, 0x00,
    0x00, 0x00, 0x00, 0x01, 0x80, 0x00, 0x00, 0x1f, 0xc0, 0x00, 0x31, 0x80, 0x00, 0x00, 0x00, 0x00,
    0x1f, 0xe0, 0x03, 0x01, 0x80, 0x00, 0x00, 0x30, 0x70, 0x00, 0x21, 0x80, 0x00, 0x00, 0x00, 0x00,
    0x10, 0x20, 0x03, 0x00, 0xc7, 0x80, 0x00, 0x20, 0x18, 0xf0, 0x61, 0x80, 0x00, 0x00, 0x00, 0x00,
    0x18, 0x00, 0x03, 0x3e, 0xcc, 0xc0, 0xc0, 0x04, 0x19, 0x98, 0x61, 0x80, 0x00, 0x00, 0x00, 0x00,
    0x1c, 0x01, 0xf3, 0x77, 0xd8, 0xc7, 0xe0, 0x06, 0x33, 0x18, 0x61, 0x8f, 0x88, 0x00, 0x00, 0x00,
    0x06, 0x03, 0x3b, 0x61, 0xd0, 0xc6, 0x00, 0x07, 0xe2, 0x18, 0x61, 0x98, 0xd8, 0x04, 0x00, 0x00,
    0x01, 0xc6, 0x0b, 0x60, 0xd9, 0x86, 0x00, 0x06, 0x03, 0x30, 0xff, 0xb0, 0x78, 0x66, 0x00, 0x00,
    0x40, 0xe4, 0x0f, 0x60, 0xdf, 0x06, 0x00, 0x07, 0x03, 0xe0, 0x31, 0xe0, 0x78, 0x62, 0x00, 0x00,
    0x40, 0x3c, 0x0f, 0x61, 0xd8, 0x06, 0x00, 0x07, 0x83, 0x00, 0x31, 0xe0, 0x78, 0x63, 0x00, 0x00,
    0x60, 0x36, 0x1b, 0x63, 0xc8, 0x02, 0x00, 0x02, 0xc1, 0x00, 0x18, 0xb0, 0xcc, 0xe2, 0x00, 0x00,
    0x30, 0x33, 0x3b, 0x36, 0x4e, 0x03, 0x00, 0x02, 0x61, 0xc0, 0x0c, 0x99, 0xcd, 0xfe, 0x00, 0x00,
    0x0f, 0xe1, 0xe1, 0x3c, 0x03, 0xf3, 0x00, 0x02, 0x38, 0x7e, 0x0c, 0x8f, 0x07, 0x9c, 0x00, 0x00,
    0x00, 0x00, 0x00, 0x00, 0x00, 0x00, 0x00, 0x00, 0x08, 0x00, 0x00, 0x00, 0x00, 0x00, 0x00, 0x00,
    0x00, 0x00, 0x00, 0x18, 0x00, 0x00, 0x00, 0x00, 0x00, 0x00, 0x00, 0x00, 0x00, 0x00, 0x00, 0x00,
    0x7f, 0x84, 0x00, 0x18, 0x00, 0x00, 0x00, 0x00, 0x00, 0x00, 0x00, 0x00, 0x00, 0x00, 0x00, 0x00,
    0xc0, 0xe4, 0x00, 0x18, 0x38, 0x00, 0x00, 0x00, 0x00, 0x00, 0x00, 0x00, 0x00, 0x00, 0x00, 0x00,
    0x04, 0x3c, 0x3c, 0x18, 0x6c, 0x00, 0x00, 0x00, 0x00, 0x00, 0x00, 0x00, 0x00, 0x00, 0x00, 0x00,
    0x04, 0x1e, 0x06, 0x7f, 0xc6, 0x00, 0x00, 0x00, 0x00, 0x00, 0x00, 0x00, 0x00, 0x00, 0x00, 0x00,
    0x04, 0x3e, 0x03, 0x18, 0x86, 0x00, 0x00, 0x00, 0x00, 0x00, 0x00, 0x00, 0x00, 0x00, 0x00, 0x00,
    0x04, 0x36, 0x7f, 0x19, 0x8c, 0x00, 0x00, 0x00, 0x00, 0x00, 0x00, 0x00, 0x00, 0x00, 0x00, 0x00,
    0x07, 0xe6, 0xc7, 0x19, 0xf8, 0x00, 0x00, 0x00, 0x00, 0x00, 0x00, 0x00, 0x00, 0x00, 0x00, 0x00,
    0x06, 0x07, 0x83, 0x18, 0x80, 0x00, 0x00, 0x00, 0x00, 0x00, 0x00, 0x00, 0x00, 0x00, 0x00, 0x00,
    0x06, 0x07, 0x81, 0x18, 0xc0, 0x00, 0x00, 0x00, 0x00, 0x00, 0x00, 0x00, 0x00, 0x00, 0x00, 0x00,
    0x06, 0x06, 0xc3, 0x98, 0x70, 0x00, 0x00, 0x00, 0x00, 0x00, 0x00, 0x00, 0x00, 0x00, 0x00, 0x00,
    0x02, 0x04, 0x7e, 0x08, 0x3f, 0x80, 0x00, 0x00, 0x00, 0x00, 0x00, 0x00, 0x00, 0x00, 0x00, 0x00};
static const uint8_t logo_width = 128;
static const uint8_t logo_height = 27;

// Heating Animation
static const uint8_t PROGMEM heat_animate[] = {
    0b00000001, 0b00000000, 0b00000001, 0b10000000, 0b00000001, 0b10000000, 0b00000001, 0b01000000,
    0b00000010, 0b01000000, 0b00100010, 0b01000100, 0b00100100, 0b00100100, 0b01010101, 0b00100110,
    0b01001001, 0b10010110, 0b10000010, 0b10001001, 0b10100100, 0b01000001, 0b10011000, 0b01010010,
    0b01000100, 0b01100010, 0b00100011, 0b10000100, 0b00011000, 0b00011000, 0b00000111, 0b11100000};
static const uint8_t heat_animate_width = 16;
static const uint8_t heat_animate_height = 16;

// Tick
static const uint8_t PROGMEM tick[] = {
    0b00000000, 0b00000100, 0b00000000, 0b00001010, 0b00000000, 0b00010101, 0b00000000, 0b00101010,
    0b00000000, 0b01010100, 0b00000000, 0b10101000, 0b00000001, 0b01010000, 0b00100010, 0b10100000,
    0b01010101, 0b01000000, 0b10101010, 0b10000000, 0b01010101, 0b00000000, 0b00101010, 0b00000000,
    0b00010100, 0b00000000, 0b00001000, 0b00000000, 0b01111111, 0b11100000};
static const uint8_t tick_width = 16;
static const uint8_t tick_height = 15;

// This needs to be specified or the compiler will fail as you can't initialize a
// flexible array member in a nested context
#define MAX_PROFILE_LENGTH 8

// TODO(HEIDT) may need to switch away from floats for speed/sizeA
struct solder_profile_t {
    uint8_t points;
    float seconds[MAX_PROFILE_LENGTH];
    float fraction[MAX_PROFILE_LENGTH];
};

// TODO(HEIDT) how to adjust for environments where the board starts hot or cold?
// profiles pulled from here: https://www.compuphase.com/electronics/reflowsolderprofiles.htm#_
#define NUM_PROFILES 2
const static solder_profile_t profiles[NUM_PROFILES] = {
    {.points = 4, .seconds = {90, 180, 240, 260}, .fraction = {.65, .78, 1.00, 1.00}},
    {.points = 2, .seconds = {162.0, 202.0}, .fraction = {.95, 1.00}}};

// temperature must be within this range to move on to next step
#define TARGET_TEMP_THRESHOLD 2.5

// PID values
float kI = 0.2;
float kD = 0.25;
float kP = 4.0;
float I_clip = 220;
float error_I = 0;

// Optional temperature sensor
OneWire oneWire(ONE_WIRE_BUS);
DallasTemperature sensors(&oneWire);
int sensor_count = 0;
DeviceAddress temp_addresses[3];

SimpleKalmanFilter tempKalmanFilter(1, 1, 0.01);
SimpleKalmanFilter voltKalmanFilter(1, 1, 0.01);

#define DEBUG

#ifdef DEBUG
#define debugprint(x) Serial.print(x);
#define debugprintln(x) Serial.println(x);
#else
#define debugprint(x)
#define debugprintln(x)
#endif

// -------------------- Function prototypes -----------------------------------
void inline heatAnimate(int &x, int &y, float v, float t, float target_temp);

// -------------------- Function definitions ----------------------------------

void dnsw_change_isr() {
    dn_button_state = BUTTON_PRESSED;
    down_state_change_time = millis();
}

void upsw_change_isr() {
    up_button_state = BUTTON_PRESSED;
    up_state_change_time = millis();
}

void setup() {

    // Pin Direction control
    pinMode(MOSFET_PIN, OUTPUT);
    pinMode(UPSW_PIN, INPUT);
    pinMode(DNSW_PIN, INPUT);
    pinMode(TEMP_PIN, INPUT);
    pinMode(VCC_PIN, INPUT);
    pinMode(LED_GREEN_PIN, OUTPUT);

    digitalWrite(LED_GREEN_PIN, HIGH);
    analogWrite(MOSFET_PIN, 255); // VERY IMPORTANT, DONT CHANGE!

    attachInterrupt(DNSW_PIN, dnsw_change_isr, FALLING);
    attachInterrupt(UPSW_PIN, upsw_change_isr, FALLING);

    Serial.begin(9600);

    // Enable Fast PWM with no prescaler
    setFastPwm();
    setVREF();

    // Start-up Diplay
    debugprintln("Showing startup");
    showLogo();

    debugprintln("Checking sensors");
    // check onewire TEMP_PIN sensors
    setupSensors();

    debugprintln("Checking first boot");
    if (isFirstBoot() || !validateCRC()) {
        doSetup();
    }

    // Pull saved values from EEPROM
    max_temp_index = getMaxTempIndex();
    bed_resistance = getResistance();

    debugprintln("Entering main menu");
    // Go to main menu
    mainMenu();
}

void updateCRC() {
    uint32_t new_crc = eepromCRC();
    setCRC(new_crc);
}

bool validateCRC() {
    uint32_t stored_crc;
    EEPROM.get(CRC_ADDR, stored_crc);
    uint32_t calculated_crc = eepromCRC();
    debugprint("got CRCs, stored: ");
    debugprint(stored_crc);
    debugprint(", calculated: ");
    debugprintln(calculated_crc);
    return stored_crc == calculated_crc;
}

void setCRC(uint32_t new_crc) { EEPROM.put(CRC_ADDR, new_crc); }

uint32_t eepromCRC(void) {
    static const uint32_t crc_table[16] = {0x00000000, 0x1db71064, 0x3b6e20c8, 0x26d930ac,
                                           0x76dc4190, 0x6b6b51f4, 0x4db26158, 0x5005713c,
                                           0xedb88320, 0xf00f9344, 0xd6d6a3e8, 0xcb61b38c,
                                           0x9b64c2b0, 0x86d3d2d4, 0xa00ae278, 0xbdbdf21c};
    uint32_t crc = ~0L;
    // Skip first 4 bytes of EEPROM as thats where we store the CRC
    for (int index = 4; index < EEPROM.length(); ++index) {
        crc = crc_table[(crc ^ EEPROM[index]) & 0x0f] ^ (crc >> 4);
        crc = crc_table[(crc ^ (EEPROM[index] >> 4)) & 0x0f] ^ (crc >> 4);
        crc = ~crc;
    }

    return crc;
}

inline void setupSensors() {
    sensors.begin();
    sensor_count = sensors.getDeviceCount();
    debugprint("Looking for sensors, found: ");
    debugprintln(sensor_count);
    for (int i = 0; i < min(sensor_count, sizeof(temp_addresses)); i++) {
        sensors.getAddress(temp_addresses[i], i);
    }
}

inline void setFastPwm() { analogWriteFrequency(64); }

inline void setVREF() { analogReference(INTERNAL1V5); }

inline bool isFirstBoot() {
    uint8_t first_boot = EEPROM.read(FIRSTTIME_BOOT_ADDR);
    debugprint("Got first boot flag: ");
    debugprintln(first_boot);
    return first_boot != 1;
}

inline void setFirstBoot() {
    EEPROM.write(FIRSTTIME_BOOT_ADDR, 1);
    updateCRC();
}

inline float getResistance() {
    float f;
    return EEPROM.get(RESISTANCE_INDEX_ADDR, f);
    return f;
}

inline void setResistance(float resistance) {
    EEPROM.put(RESISTANCE_INDEX_ADDR, resistance);
    updateCRC();
}

inline void setMaxTempIndex(int index) {
    EEPROM.update(TEMP_INDEX_ADDR, index);
    updateCRC();
}

inline int getMaxTempIndex(void) { return EEPROM.read(TEMP_INDEX_ADDR) % sizeof(max_temp_array); }

void showLogo() {
    unsigned long start_time = millis();
    display.begin(SSD1306_SWITCHCAPVCC, SCREEN_ADDRESS);
    while (start_time + 2000 > millis()) {
        display.clearDisplay();
        display.setTextSize(1);
        display.setTextColor(SSD1306_WHITE);
        display.setCursor(0, 0);
        display.drawBitmap(0, 0, logo, logo_width, logo_height, SSD1306_WHITE);
        display.setCursor(80, 16);
        display.print(F("S/W V"));
        display.print(sw, 1);
        display.setCursor(80, 24);
        display.print(F("H/W V"));
        display.print(hw, 1);
        display.display();
        buttons_state_t cur_button = getButtonsState();
        // If we press both buttons during boot, we'll enter the setup process
        if (cur_button == BUTTONS_BOTH_PRESS) {
            doSetup();
            return;
        }
    }
}

inline void doSetup() {
    debugprintln("Performing setup");
    // TODO(HEIDT) show an info screen if we're doing firstime setup or if memory is corrupted

    getResistanceFromUser();
    // TODO(HEIDT) do a temperature module setup here

    setFirstBoot();
}

inline void getResistanceFromUser() {
    float resistance = 1.88;
    while (1) {
        clearMainMenu();
        display.setCursor(3, 4);
        display.print(F("Resistance"));
        display.drawLine(3, 12, 79, 12, SSD1306_WHITE);
        display.setCursor(3, 14);
        display.print(F("UP/DN: change"));
        display.setCursor(3, 22);
        display.print(F("BOTH: choose"));
        buttons_state_t button = getButtonsState();
        if (button == BUTTONS_UP_PRESS) {
            resistance += 0.01;
        } else if (button == BUTTONS_DN_PRESS) {
            resistance -= 0.01;
        } else if (button == BUTTONS_BOTH_PRESS) {
            setResistance(resistance);
            return;
        }
        resistance = constrain(resistance, 0, MAX_RESISTANCE);

        display.setCursor(90, 12);
        display.print(resistance);
        display.display();
    }
}

inline void mainMenu() {
    // Debounce
    menu_state_t cur_state = MENU_IDLE;

    int x = 0;   // Display change counter
    int y = 200; // Display change max (modulused below)
    uint8_t profile_index = 0;

    while (1) {
        switch (cur_state) {
        case MENU_IDLE: {
            clearMainMenu();
            buttons_state_t cur_button = getButtonsState();

            if (cur_button == BUTTONS_BOTH_PRESS) {
                cur_state = MENU_SELECT_PROFILE;
            } else if (cur_button == BUTTONS_UP_PRESS) {
                cur_state = MENU_INC_TEMP;
            } else if (cur_button == BUTTONS_DN_PRESS) {
                cur_state = MENU_DEC_TEMP;
            }
        } break;
        case MENU_SELECT_PROFILE: {
            debugprintln("getting thermal profile");
            profile_index = getProfile();
            cur_state = MENU_HEAT;
        } break;
        case MENU_HEAT: {
            if (!heat(max_temp_array[max_temp_index], profile_index)) {
                cancelledPB();
                coolDown();
            } else {
                coolDown();
                completed();
            }
            cur_state = MENU_IDLE;
        } break;
        case MENU_INC_TEMP: {
            if (max_temp_index < sizeof(max_temp_array) - 1) {
                max_temp_index++;
                debugprintln("incrementing max temp");
                setMaxTempIndex(max_temp_index);
            }
            cur_state = MENU_IDLE;
        } break;
        case MENU_DEC_TEMP: {
            if (max_temp_index > 0) {
                max_temp_index--;
                debugprintln("decrementing max temp");
                setMaxTempIndex(max_temp_index);
            }
            cur_state = MENU_IDLE;
        } break;
        }

        // Change Display (left-side)
        showMainMenuLeft(x, y);

        // Update Display (right-side)
        showMainMenuRight();
    }
}

#define BUTTON_PRESS_TIME 150
buttons_state_t getButtonsState() {
    single_button_state_t button_dn;
    single_button_state_t button_up;
    unsigned long button_dn_time;
    unsigned long button_up_time;

    noInterrupts();
    button_dn = dn_button_state;
    button_up = up_button_state;
    button_dn_time = down_state_change_time;
    button_up_time = up_state_change_time;
    interrupts();

    unsigned long cur_time = millis();
    buttons_state_t state = BUTTONS_NO_PRESS;

    if (button_dn == BUTTON_PRESSED && button_up == BUTTON_PRESSED &&
        abs(button_dn_time - button_up_time) < BUTTON_PRESS_TIME) {
        if (cur_time - button_dn_time > BUTTON_PRESS_TIME &&
            cur_time - button_up_time > BUTTON_PRESS_TIME) {
            state = BUTTONS_BOTH_PRESS;
            noInterrupts();
            dn_button_state = BUTTON_NO_ACTION;
            up_button_state = BUTTON_NO_ACTION;
            interrupts();
        }
    } else if (button_up == BUTTON_PRESSED && cur_time - button_up_time > BUTTON_PRESS_TIME) {
        state = BUTTONS_UP_PRESS;
        noInterrupts();
        up_button_state = BUTTON_NO_ACTION;
        interrupts();
    } else if (button_dn == BUTTON_PRESSED && cur_time - button_dn_time > BUTTON_PRESS_TIME) {
        state = BUTTONS_DN_PRESS;
        noInterrupts();
        dn_button_state = BUTTON_NO_ACTION;
        interrupts();
    }

    return state;
}

inline uint8_t getProfile() {
    uint8_t cur_profile = 0;
    while (1) {
        clearMainMenu();
        display.setCursor(3, 4);
        display.print(F("Pick profile"));
        display.drawLine(3, 12, 79, 12, SSD1306_WHITE);
        display.setCursor(3, 14);
        display.print(F(" UP/DN: cycle"));
        display.setCursor(3, 22);
        display.print(F(" BOTH: choose"));
        buttons_state_t cur_button = getButtonsState();
        if (cur_button == BUTTONS_BOTH_PRESS) {
            clearMainMenu();
            return cur_profile;
        } else if (cur_button == BUTTONS_DN_PRESS) {
            cur_profile--;
        } else if (cur_button == BUTTONS_UP_PRESS) {
            cur_profile++;
        }
        cur_profile %= NUM_PROFILES;
        displayProfileRight(cur_profile);
        display.display();
    }
}

inline void displayProfileRight(int8_t cur_profile) {
    int cur_x = 90;
    int cur_y = 30;
    // start at x=90, go to SCREEN_WIDTH-8, save 6 pixels for cooldown
    float x_dist = SCREEN_WIDTH - 90 - 8;
    display.setCursor(cur_x, cur_y);
    float total_seconds = (int)profiles[cur_profile].seconds[profiles[cur_profile].points - 1];

    for (int i = 0; i < profiles[cur_profile].points; i++) {
        int x_next = (int)((profiles[cur_profile].seconds[i] / total_seconds) * x_dist) + 90;
        int y_next = 30 - (int)(profiles[cur_profile].fraction[i] * 28.0);
        display.drawLine(cur_x, cur_y, x_next, y_next, SSD1306_WHITE);
        cur_x = x_next;
        cur_y = y_next;
    }
    // draw down to finish TEMP_PIN
    display.drawLine(cur_x, cur_y, SCREEN_WIDTH - 2, 30, SSD1306_WHITE);
}

inline void clearMainMenu() {
    display.clearDisplay();
    display.setTextSize(1);
    display.drawRoundRect(0, 0, 83, 32, 2, SSD1306_WHITE);
}

inline void showMainMenuLeft(int &x, int &y) {
    if (x < (y * 0.5)) {
        display.setCursor(3, 4);
        display.print(F("PRESS BUTTONS"));
        display.drawLine(3, 12, 79, 12, SSD1306_WHITE);
        display.setCursor(3, 14);
        display.print(F(" Change  MAX"));
        display.setCursor(3, 22);
        display.print(F(" Temperature"));
    } else {
        display.setCursor(3, 4);
        display.print(F("HOLD  BUTTONS"));
        display.drawLine(3, 12, 79, 12, SSD1306_WHITE);
        display.setCursor(3, 18);
        display.print(F("Begin Heating"));
    }
    x = (x + 1) % y; // Display change increment and modulus
}

inline void showMainMenuRight() {
    display.setCursor(95, 6);
    display.print(F("TEMP"));
    display.setCursor(95, 18);
    display.print(max_temp_array[max_temp_index]);
    display.print(F("C"));
    display.display();
}

inline void showHeatMenu(byte max_temp) {
    display.clearDisplay();
    display.setTextSize(2);
    display.setCursor(22, 4);
    display.print(F("HEATING"));
    display.setTextSize(1);
    display.setCursor(52, 24);
    display.print(max_temp);
    display.print(F("C"));
    display.display();
}
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
void loop() {
    // Not used
}

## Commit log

2023-05-09 Add files via upload
    Changed so that it no longer causes 12V 5A supply to reset
    [pcb_reflow_fw.ino]
2023-05-09 Update pcb_reflow_fw.ino
    Adjust PWM conditions after overshoot
    [pcb_reflow_fw.ino]
2023-06-08 Add BOM
    [Heatplate_v1.2 BOM.csv]
2023-06-08 interactive bom
